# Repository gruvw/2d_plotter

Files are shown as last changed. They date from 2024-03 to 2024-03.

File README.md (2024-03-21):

# 2D Plotter Robot

Lucas Jung 324724 ([@gruvw](https://gruvw.com))

EPFL BA6 / MIT CS-358 / 2D Plotter Robot / Personal Project

This **2D Plotter Robot** is a device that can draw user defined drawings on a small sheet of paper based on a provided computer program.



**Note**: this README was also made available as a **PDF** for portability purposes (see `README.pdf`). However, the video won't work and the layout is not perfect on the PDF version (see `README.md` for Markdown based document).

## Result

Here are a few pictures showing the final plotter from different angles.

<div>
    
    
    
    
    
    
</div>

### Drawings

You can see below some pictures of the drawings that the plotter achieved to draw.

<div>
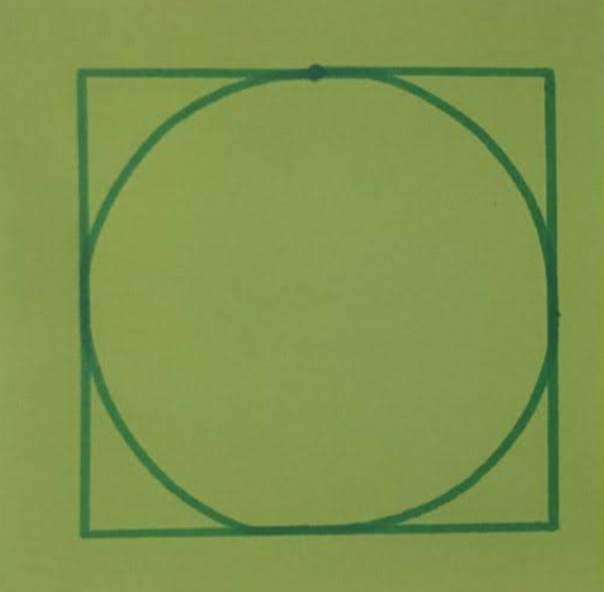
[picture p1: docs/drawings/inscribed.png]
    
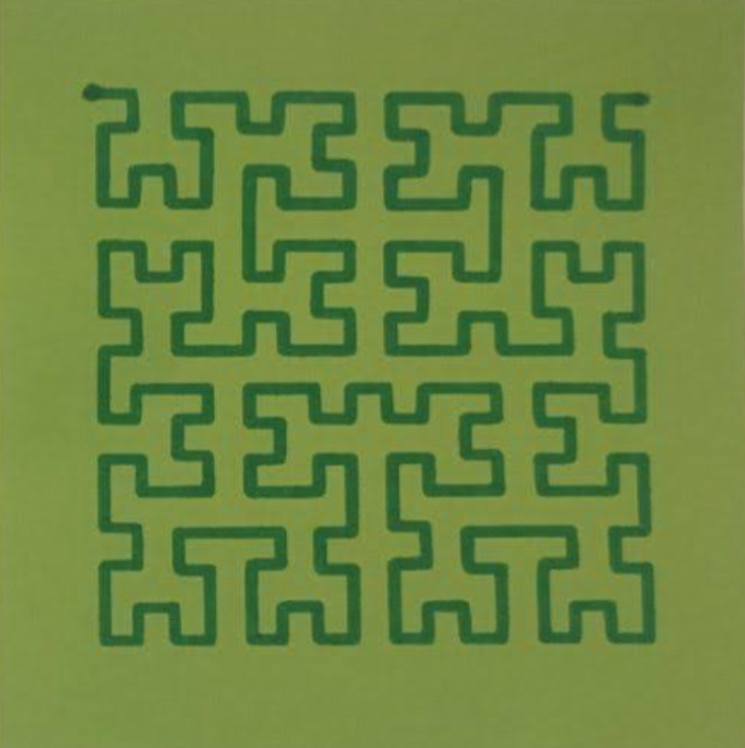
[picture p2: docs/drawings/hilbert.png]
    
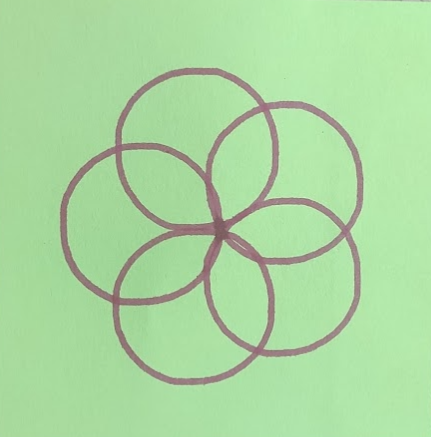
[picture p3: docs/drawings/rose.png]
    
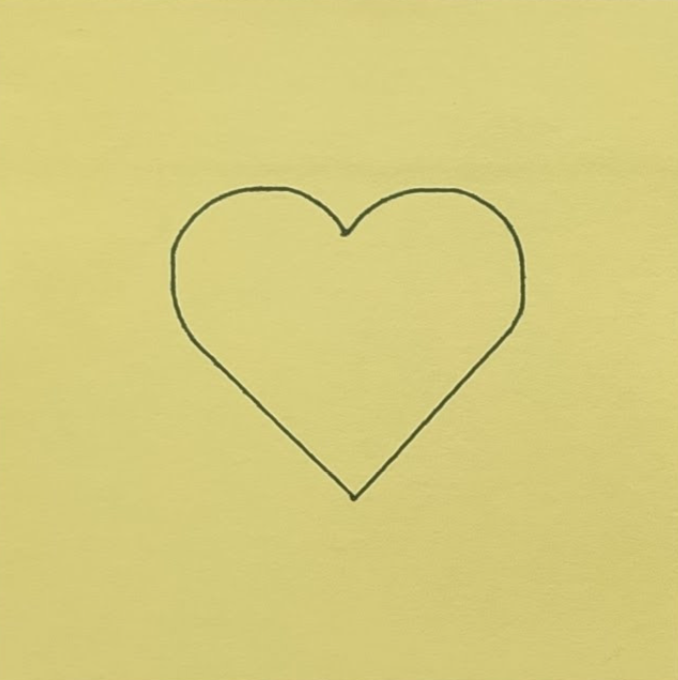
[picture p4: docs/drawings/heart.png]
    
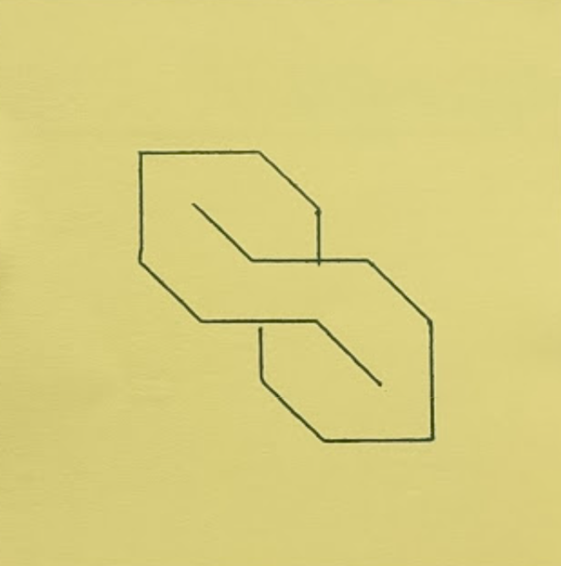
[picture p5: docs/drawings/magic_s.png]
    
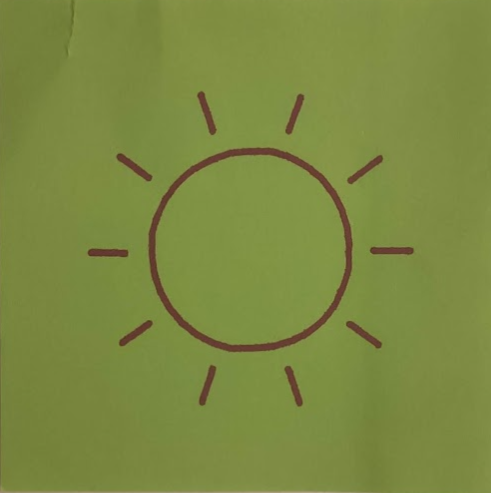
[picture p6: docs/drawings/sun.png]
    
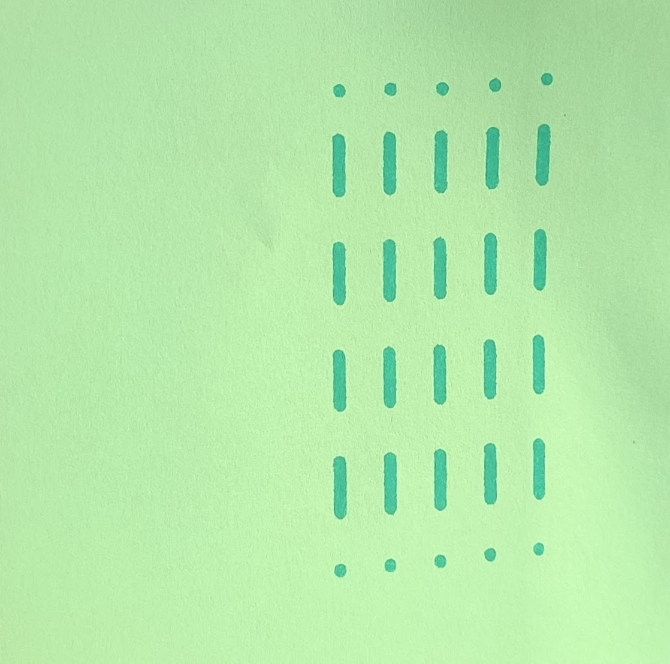
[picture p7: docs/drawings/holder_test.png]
    
</div>

Most of the drawings have an impressive precision.  
However, I noticed a small loss of precision when drawing with the 3D printed dynamic penholder.
It is due to a small amount of play that occurs with the moving piece slightly tilting the pen.
It is not noticeable for most of the drawings.

### Video Demonstration

Here is a short video (click on thumbnail to watch) demonstrating the plotter drawing a dashed line.

<a href="https://youtu.be/-nplPBwFOKw">
    Video demo of the 2D plotter robot
</a>

**Note**: Link of the video for accessibility purposes <https://youtu.be/-nplPBwFOKw>.

## Technical informations

The code for the project was mostly written in **C** (a few `.cpp` and `.ino` were required to interact with the [Arduino](https://www.arduino.cc/) ecosystem).  
To add a bit more to the challenge, I also decided not to use any external libraries (except for the `Arduino.h`).
I wrote the code that manages the servo and the steppers from scratch (see `2d_plotter/src/hardware` for more information).

### Project structure

A short explanation of the project structure in this directory:

- `2d_plotter/src`: contains the source code for the project.
    - `draw/`: basic drawing functionalities.
    - `hardware/`: abstraction layer used to interact with hardware components, exposes helpful functions to control the servo and the steppers in a safe way (automatic software limits).
    - `main/`: entry point of the program along with the three procedures `square_inscribe_circle`, `hilbert_filling`, `turtle_REPL`.
    - `turtle/`: the implementation of the turtle language interpreter.
- `CAD/`: contains all the computer designs.
    - `exports/`: the `.stl` files for the different parts.
- `docs/`: hosts the images used in this README.
- `turtle/`: contains examples of turtle programs that can run on the 2D plotter.

### Turtle language

This project implements a turtle language interpreter/[REPL](https://en.wikipedia.org/wiki/Read–eval–print_loop) (Read Eval Print Loop).

**Note**: learn more about the turtle language here <https://turtleacademy.com/playground>.

No modifications have been made to the original syntax of the language.
It supports multi-lines input (with indentation) and it is not spacing dependent.

You can find examples of programs that ran on the plotter in the `turtle` directory (`.turtle` files).  
The programs should be sent to the Arduino by using the Serial Input monitor.

### Additional information

I added a few other things to the project:

- Two limit switches are used to automatically set the "home"/origin position of the plotter. Before running a program, the plotter will initiate a setup procedure by moving up to the limit switch (in each direction) in order to reset to the home position without human intervention.
- I extended the original turtle instruction set to support the following instructions:
    - `backward <dist>`: goes backward for `<dist>` steps.
    - `circle <radius>`: draws a circle from current position and heading (rotated circle around starting point) of the given `<radius>`.
    - `home`: to return to the home position (always on the same exact spot thanks to the limit switches).
    - `setheading <angle>`: sets the heading of the turtle to the given `<angle>`, useful to rotate drawings (uses a 2D rotation matrix).
- I also added a buzzer connected to the arduino. It gives a nice audio feedback to the person using the plotter about the current state of the procedure (started, ready to draw, finished).
- Well structured source code with abstraction layers over the hardware and drawing functions (directory based separation of concerns).
- Extended documentation, both in the code with comments and here on the `README.md`.

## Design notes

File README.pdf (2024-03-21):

## 2D Plotter Robot

Lucas Jung ([@gruvw](https://gruvw.com))

EPFL BA6 / MIT CS-358 / 2D Plotter Robot / Personal Project

This 2D Plotter Robot is a device that can draw user defined drawings on a small sheet of paper based on a provided computer program.

Result

Here are a few pictures showing the final plotter from different angles.

Drawings

You can see below some pictures of the drawings that the plotter achieved to draw.

<img src="docs/drawings/inscribed.png" width="170">
<img src="docs/drawings/hilbert.png" width="170"> <img src="docs/drawings/rose.png" width="170">
<img src="docs/drawings/sun.png" width="170">
<img src="docs/drawings/holder_test.png" width="170">

Video Demonstration

Here is a short video (click on thumbnail to watch) demonstrating the functioning of the plotter.

Technical informations

The code for the project was mostly written in C (a few .cpp and .ino when required to interact with the Arduino ecosystem).
To add a little bit more challenge, I also decided not to use any external libraries (except for the Arduino.h). I wrote the code that manages the servo and the steppers from scratch.

Project structure

A short explanation of the structure of this repository:

- 2d_plotter/src: contains the source code for the project.
– draw/: basic drawing functionality.
– hardware/: abstraction layer used to interact with hardware components, exposes helpful functions to control the servo and the steppers in a safe way.
– main/: entry point of the program.
– turtle/: the definition of the turtle language interpreter.
- CAD/: contains all the computer designs.

1

– exports/: the .stl files for the different parts.
- docs/: hosts the images used in this README.
- turtle/: contains examples of turtle program that can run on the 2D plotter.

Turtle language

This project implements a turtle language interpreter/REPL (Read Eval Print Loop).

Note: learn more about the turtle language here https://turtleacademy.com/pl ayground. (https://turtleacademy.com/playground)

No modifications have been made to the syntax of the language.
You can find examples of programs that run on the plotter in the turtle directory (.turtle files).
The programs should be sent to the Arduino by using the Serial Input monitor.

Improvements

I added a few things to the plotter:

- Two limit switches are used to set the “home” or origin position of the plotter. Before running a program, the plotter will set up by moving up to the limit switch (in each direction) in order to reset to the home position without human intervention.
- I extended the original turtle instruction set to support the following instructions:
– backward <dist>: goes backward for <dist> steps.
– circle <radius>: draws a circle from current position and heading (rotated circle) of the given <radius>.
– home: to return to the home position.
– setheading <angle>: sets the heading of the turtle to the given <angle>, useful to rotate drawings.
- I also added a buzzer connected to the arduino. It gives a nice audio feedback to the person using the plotter about the current state of the turtle (started, ready to draw, finished).

2

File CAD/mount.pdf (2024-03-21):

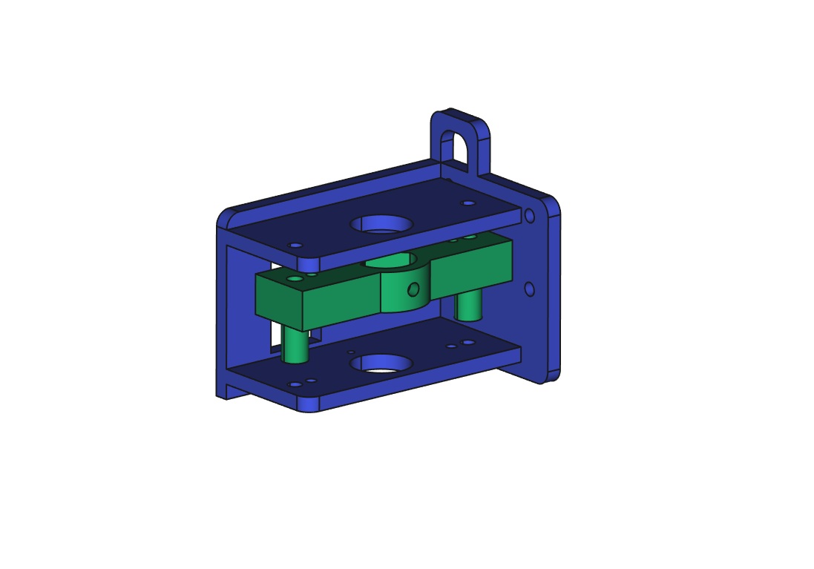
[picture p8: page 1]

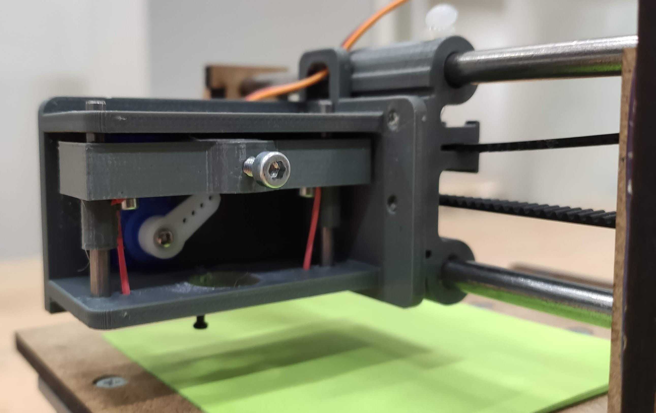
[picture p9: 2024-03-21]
docs/plotter/plotter_lifter.png

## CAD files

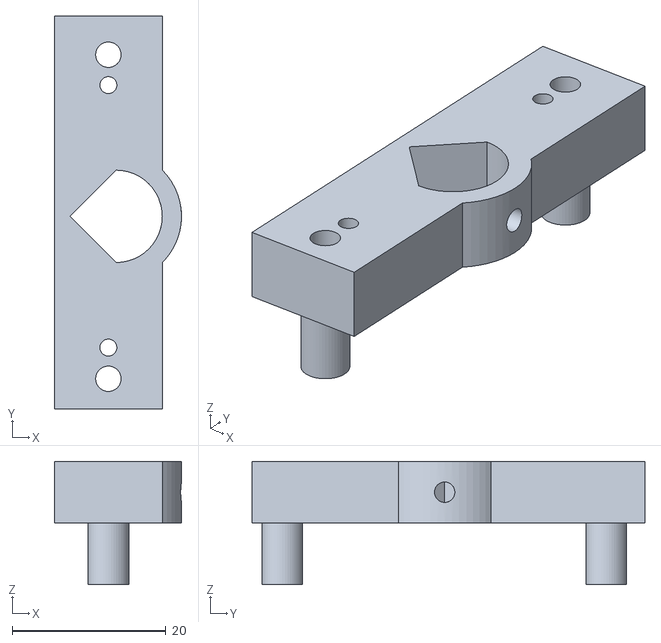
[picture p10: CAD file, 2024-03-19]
CAD/exports/pen_holder.stl
16.5 x 51.0 x 16.0

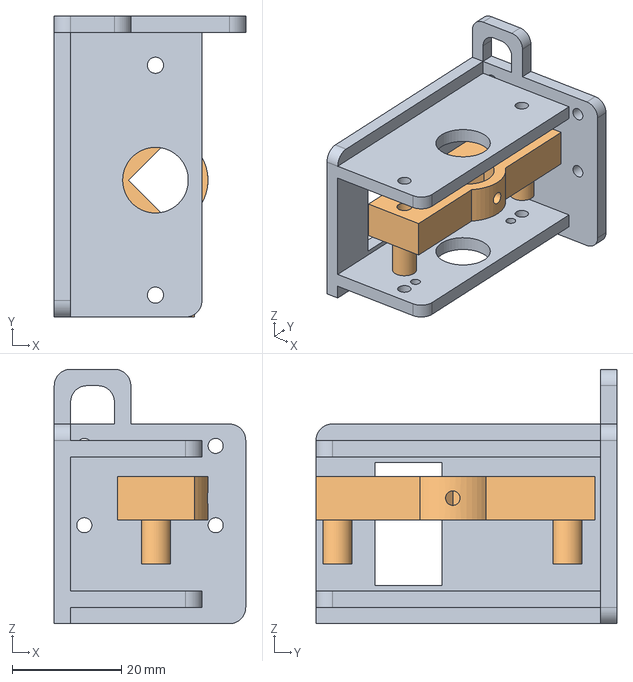
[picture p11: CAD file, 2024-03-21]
CAD/mount.FCStd
35.0 x 55.0 x 46.5 mm

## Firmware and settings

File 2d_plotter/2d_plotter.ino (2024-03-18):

extern "C" {
    #include "src/main/start.h"
}

// Standard output setup
FILE f_out;
int sput(char c, __attribute__((unused)) FILE * f) {
    return !Serial.write(c);
}

void setup() {
    // Serial input / output setup
    // cf https://www.nongnu.org/avr-libc/user-manual/group__avr__stdio.html#gaf41f158c022cbb6203ccd87d27301226
    Serial.begin(9600);
    fdev_setup_stream(&f_out, sput, nullptr, _FDEV_SETUP_WRITE);
    stdout = &f_out;

    // Program entry point
    start();
}

void loop() {
}

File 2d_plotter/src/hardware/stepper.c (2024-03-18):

#include "stepper.h"

#include <Arduino.h>

// Arduino steppers pins
#define LIMIT_PIN DD7
#define STEPPER_X_PINS {A0, A1, A2, A3}
#define STEPPER_Y_PINS {DD5, DD4, DD3, DD2}

// Stepper constants
#define STEP_DELAY delay(6)

// Static pen holder
#define LIMIT_X 600
#define LIMIT_Y 100

// Dynamic pen holder
// #define LIMIT_X 700
// #define LIMIT_Y 500

Axes2D stepper_setup() {
    pinMode(LIMIT_PIN, INPUT_PULLUP);

    Stepper X = STEPPER_X_PINS;
    Stepper Y = STEPPER_Y_PINS;
    return (Axes2D) {X, Y};
}

// Modulus operation that always results in a positive number
static inline int mod(const int a, const int b) {
    const int r = a % b;
    return r < 0 ? r + b : r;
}

// Moves the given `stepper` (without verification) one step forward if `forward` is true, backward otherwise
void step(Stepper * const stepper, const bool forward) {
    stepper->pos += forward ? 1 : -1;
    for (int p = 0; p < _STEPS; p++) {
        digitalWrite(stepper->STEP_PINS[p], (mod(stepper->pos, _STEPS) - p) == 0);
    }
}

// Moves the `stepper` to its origin along its axis
void origin_stepper(Stepper * const stepper, const int limit) {
    // Walk till limit switch hit
    while (!digitalRead(LIMIT_PIN)) {
        step(stepper, false);
        STEP_DELAY;
    }

    // Walk back to relieve switch + go to axis origin
    stepper->pos = -limit;
    while (stepper->pos != 0) {
        step(stepper, true);
        STEP_DELAY;
    }
}

void origin(Axes2D * const axes) {
    origin_stepper(&axes->X, LIMIT_X);
    origin_stepper(&axes->Y, LIMIT_Y);
}

// Returns true if the stepper can move in the given `direction`, false otherwise
static inline bool valid_direction(Stepper * const stepper, const Step direction) {
    return !(
        (direction == S_FORWARD && stepper->pos > AREA_SIDE) ||
        (direction == S_BACKWARD && stepper->pos < 0)
    );
}

// Moves the `stepper` in the given `direction` if it is possible;
// returns true if moved, false otherwise
bool apply_stepper(Stepper * const stepper, const Step direction) {
    if (direction == S_STAND || !valid_direction(stepper, direction)) {
        return false;
    }

    step(stepper, direction == S_FORWARD);
    return true;
}

void apply(Axes2D * const axes, const Step x, const Step y) {
    // Wait only if one stepper stepped, no short-circuit evaluation
    if (apply_stepper(&axes->X, x) | apply_stepper(&axes->Y, y)) {
        STEP_DELAY;
    }
}

void limit_wait() {
    while (!digitalRead(LIMIT_PIN));
}

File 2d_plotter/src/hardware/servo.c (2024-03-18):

#include "servo.h"

#include <Arduino.h>

// Servo arduino settings
#define SERVO_PIN 10
#define SERVO_BALANCE 20000
#define SERVO_WAIT 100

// Servo angles (in micro-sec) for penup / pendown
#define SERVO_PENUP 1500
#define SERVO_PENDOWN 1000

Servo servo_setup() {
    return (Servo) {SERVO_PIN, 0};
}

// Applies the given angle `time` to the `servo`
void apply_servo(Servo * servo, int time) {
    delay(SERVO_WAIT);
    digitalWrite(servo->PIN, HIGH);
    delayMicroseconds(time);
    digitalWrite(servo->PIN, LOW);
    delayMicroseconds(SERVO_BALANCE - time);
    delay(SERVO_WAIT);
}

inline void penup(Servo * servo) {
    apply_servo(servo, SERVO_PENUP);
}

inline void pendown(Servo * servo) {
    apply_servo(servo, SERVO_PENDOWN);
}

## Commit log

2024-02-28 Stepper working nolib
2024-03-01 Import stepper_lib from C code
2024-03-09 feat(plotter): start servo lib (pen up, pen down)
2024-03-12 Added designs
    [pen_plate-pen_plate.stl, pen_plate-v2.stl, pen_plate.FCStd]
2024-03-13 feat(CAD): pen holder v1
    [pen_holder-v1.stl, pen_plate-v1.stl, pen_plate-v3.stl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]
2024-03-13 fix(CAD): fixed some dimensions
    [pen_holder-v2.stl, pen_plate-v4.stl, pen_plate.FCStd]
2024-03-14 feat(CAD): holder with linear movement
    [pen_holder-v3.stl, pen_holder-v4.stl, pen_plate-v5.stl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]
2024-03-14 fix(CAD): holder m3 hole
    [pen_holder-v4.stl, pen_plate.FCStd]
2024-03-15 feat(CAD): improve design
    - Reduce top plate length
    - Rubber band integration in design (two holes on bottom plate & arm, loop)
    - Add axis stiffener
    - Add cable holder
    [pen_holder-v4.stl, pen_holder-v5.stl, pen_plate-v7.stl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]
2024-03-15 fix(turtle): for loop eval order
    [input.cpp]
2024-03-15 feat(CAD): print
    [pen_holder-v6.stl, pen_holder-v7.stl, pen_plate-v8.stl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]
2024-03-16 feat(CAD): improves screws
    [pen_holder-v8.stl, pen_plate-v9.stl, pen_plate.FCStd]
2024-03-17 refactor(CAD): renamed
    [pen_holder-v1.stl, pen_holder-v2.stl, pen_holder-v3.stl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]
2024-03-18 feat(plotter): add buzzer support
    [2d_plotter.ino, start.c]
2024-03-18 feat(CAD): redesign holder
    Centers the pen, move axes around it
    [pen_holder-v10.stl, pen_holder-v11.stl, pen_holder-v9.stl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]
2024-03-19 feat: worked on the pen holder
    [pen_holder-v12.stl, pen_holder-v13.stl, pen_plate-v12.stl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]
2024-03-20 fix(turtle): input buffer overflow (partion programs)
    [input.cpp, start.c]
2024-03-21 docs: readme improvement
    [pen_plate.FCStd]
2024-03-21 feat(draw): finished drawings
    [mount.FCStd, pen_holder-v1.stl, pen_holder-v10.stl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]
2024-03-21 feat: integrate STEP file
    [mount.FCStd]
